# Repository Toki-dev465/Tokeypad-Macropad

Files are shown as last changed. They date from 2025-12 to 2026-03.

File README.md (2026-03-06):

# Important Note
My PCB design has a slight error as the 5V on MC is connected to the VCC of OLED. Using 5V may or may not work. It could potentially damage the microcontroller and the OLED. Flashing QMK is a big pain hence I also made CircuitPython KMK firmware. Will definitely try the QMK firmware when I have time. 
# Description
IBM Model M keyboard themed macropad with a rotary encoder for volume control, 6 keys and a 0.91 inch OLED display. 

# Challenges
It was my first ever electronics project. First time using KiCad, Fusion and QMK. I spent many hours just trying to figure out how to do something by Googling and watching tutorials on YouTube. I had to redesign my schematics, PCB and 3D model numerous times. 3D modeling was much harder than I anticipated at first. Even though I made many errors, I believe this shows my learning progress because you can't learn without making mistakes. 

# Specs/BOM

- 1x XIAO RP2040
- 1x SK6812 MINI Led
- 4x M3x16 Bolt
- 4x M3 Heatset
- 6x Cherry MX Switches
- 6x Blank DSA Keycaps
- 1x I2C OLED Display Module 0.91 Inch SSD1306
- 1x Rotary Encoder Module

| Schematic | PCB Design | 3D Model |
| :---: | :---: | :---: |
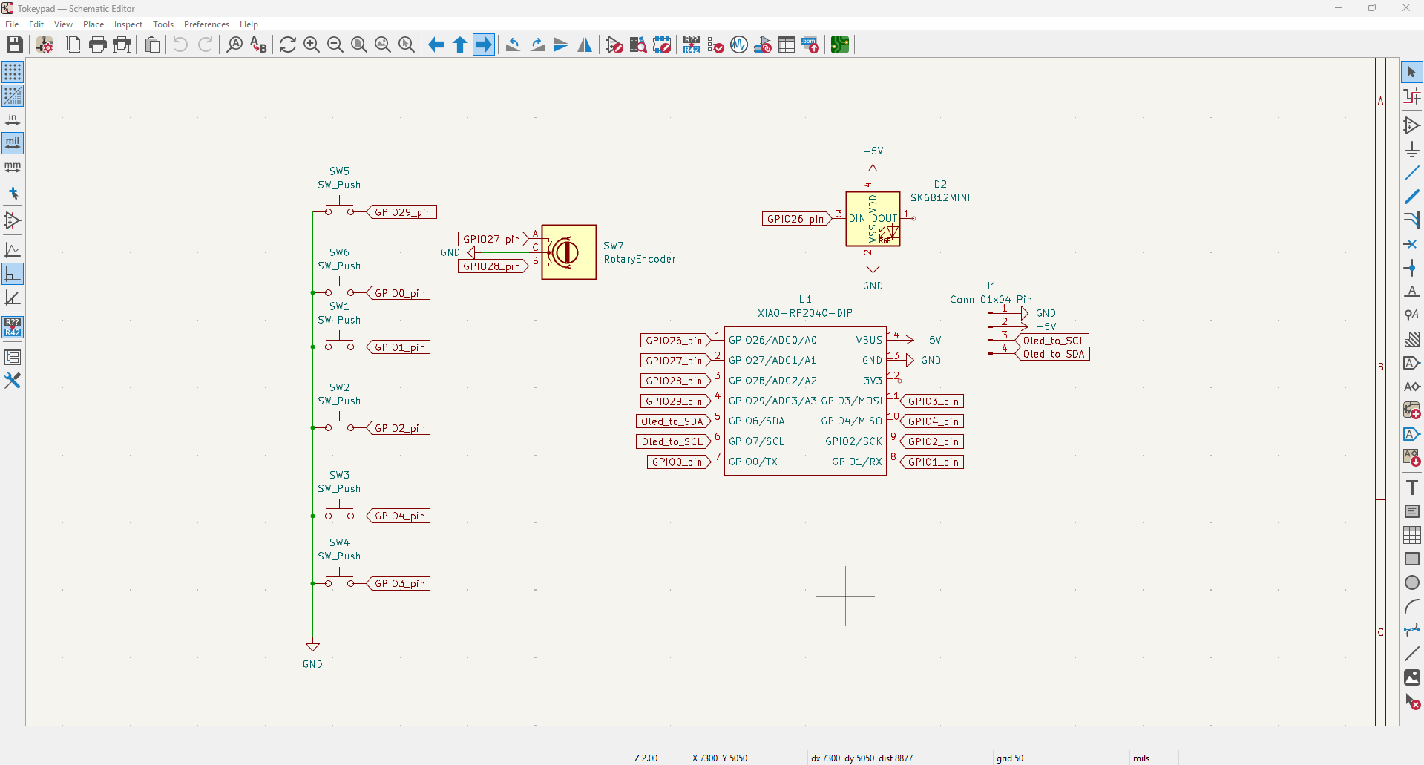
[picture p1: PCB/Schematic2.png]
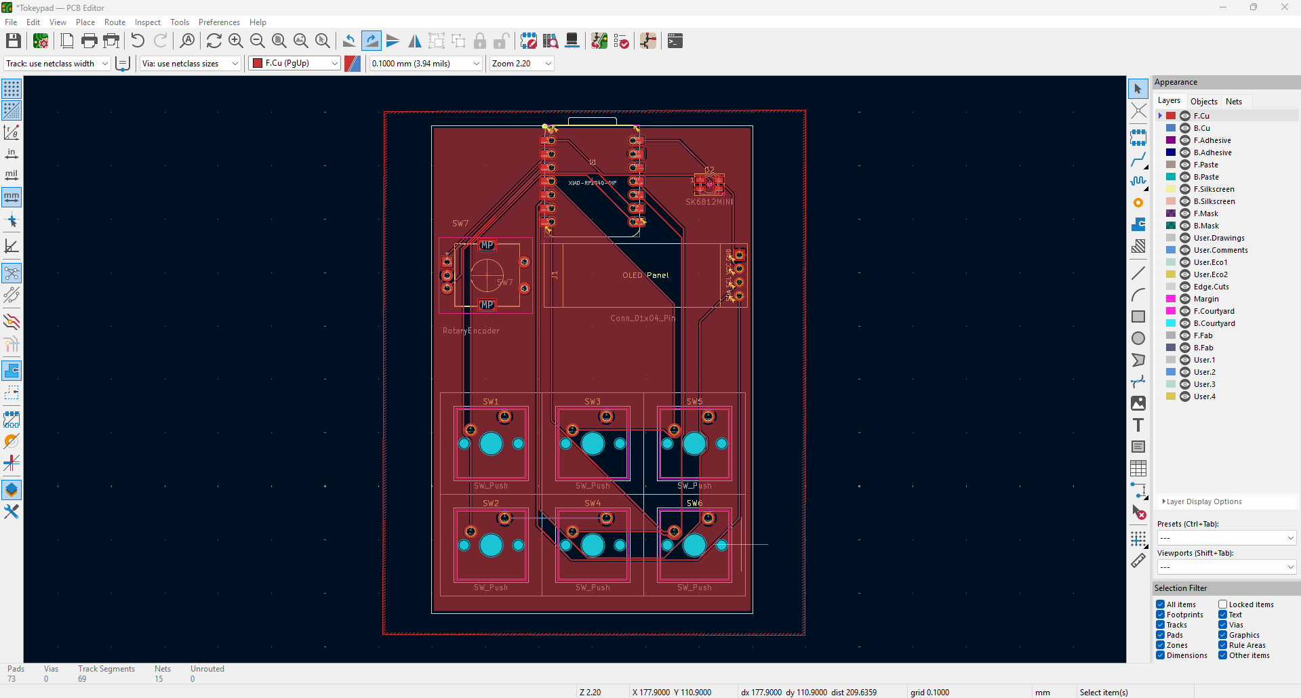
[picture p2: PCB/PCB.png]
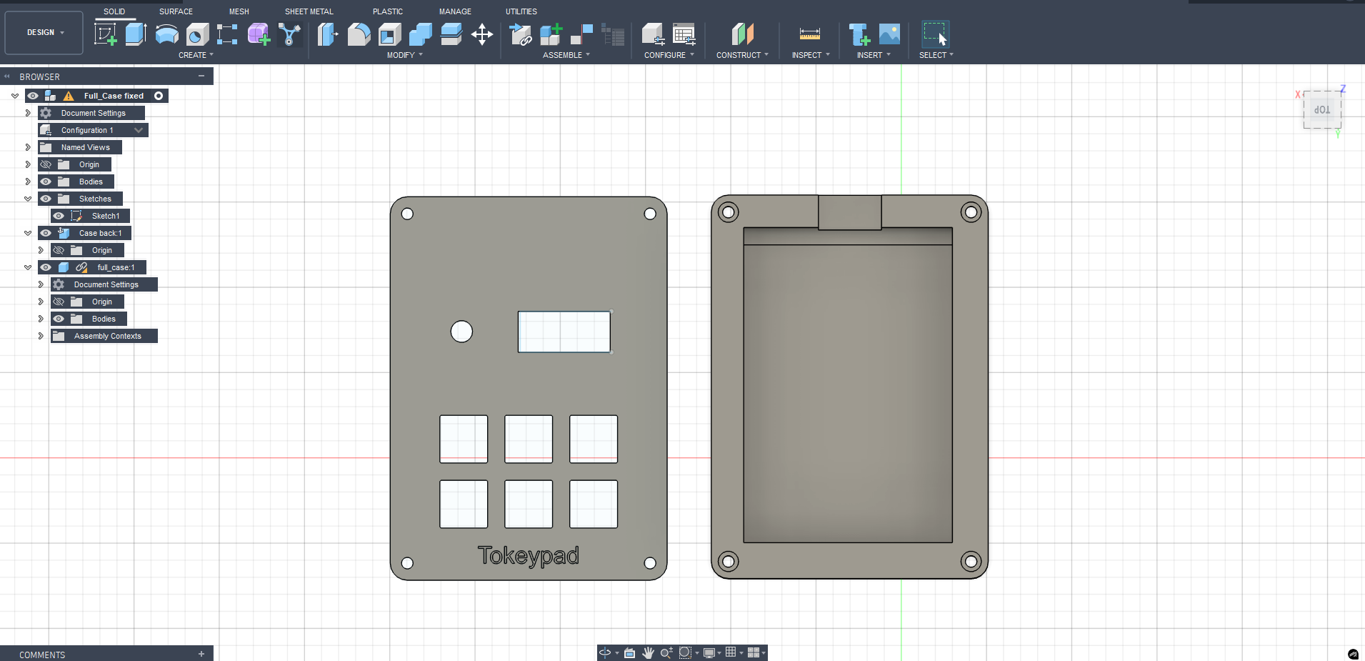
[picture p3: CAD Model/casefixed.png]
|  |  |  |
| *Circuit Diagram* | *Top/Bottom Layers* | *Fusion 360 Render* |

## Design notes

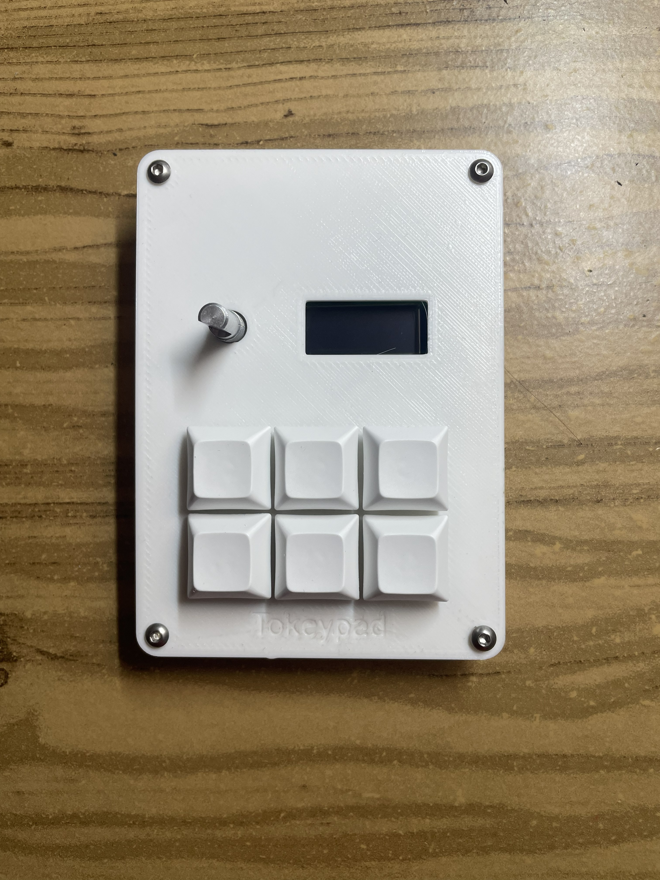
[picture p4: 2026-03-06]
Complete_pics/Tokeypad.jpeg

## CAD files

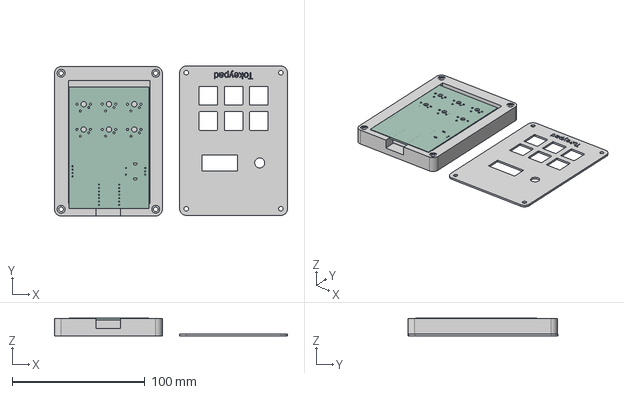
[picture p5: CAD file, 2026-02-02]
CAD Model/Full_Case.step
175.4 x 112.8 x 13.4 mm

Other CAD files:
CAD Model/Full_Case fixed.3mf

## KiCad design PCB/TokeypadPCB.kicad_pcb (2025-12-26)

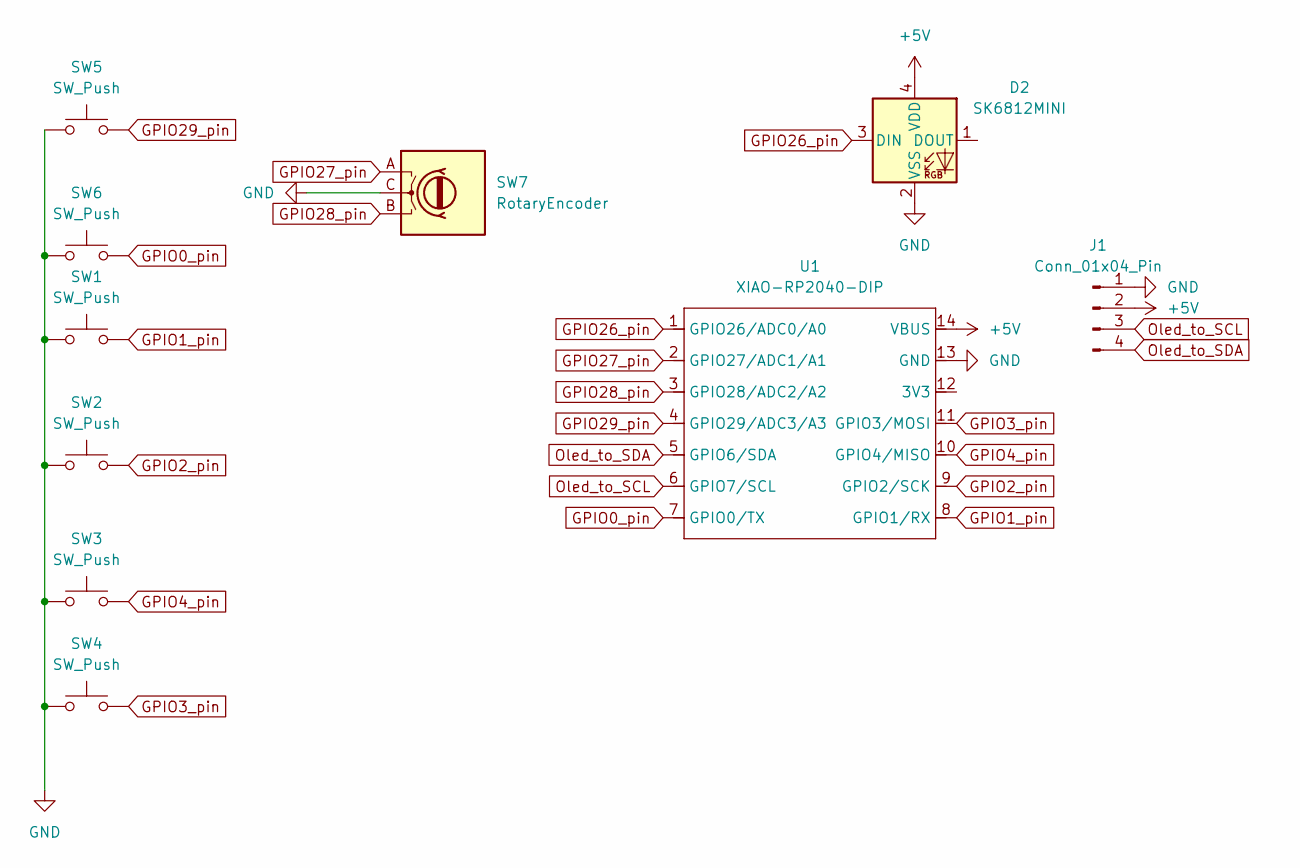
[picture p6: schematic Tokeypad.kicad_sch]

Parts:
D2: SK6812MINI; LED_SK6812MINI_PLCC4_3.5x3.5mm_P1.75mm
J1: Conn_01x04_Pin; NS-Tech_Grove_1x04_P2mm_Vertical
SW1, SW2, SW3, SW4, SW5, SW6: SW_Push; SW_Cherry_MX_1.00u_PCB
SW7: RotaryEncoder; RotaryEncoder_Alps_EC11E-Switch_Vertical_H20mm
U1: XIAO-RP2040-DIP

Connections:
+5V: D2.4 (VDD), J1.2, U1.14 (VBUS)
GND: D2.2 (VSS), J1.1, SW1.1, SW2.1, SW3.1, SW4.1, SW5.1, SW6.1, SW7.C, U1.13 (GND)
GPIO0_pin: SW6.2, U1.7 (GPIO0/TX)
GPIO1_pin: SW1.2, U1.8 (GPIO1/RX)
GPIO2_pin: SW2.2, U1.9 (GPIO2/SCK)
GPIO3_pin: SW4.2, U1.11 (GPIO3/MOSI)
GPIO4_pin: SW3.2, U1.10 (GPIO4/MISO)
GPIO26_pin: D2.3 (DIN), U1.1 (GPIO26/ADC0/A0)
GPIO27_pin: SW7.A, U1.2 (GPIO27/ADC1/A1)
GPIO28_pin: SW7.B, U1.3 (GPIO28/ADC2/A2)
GPIO29_pin: SW5.2, U1.4 (GPIO29/ADC3/A3)
Oled_to_SCL: J1.3, U1.6 (GPIO7/SCL)
Oled_to_SDA: J1.4, U1.5 (GPIO6/SDA)

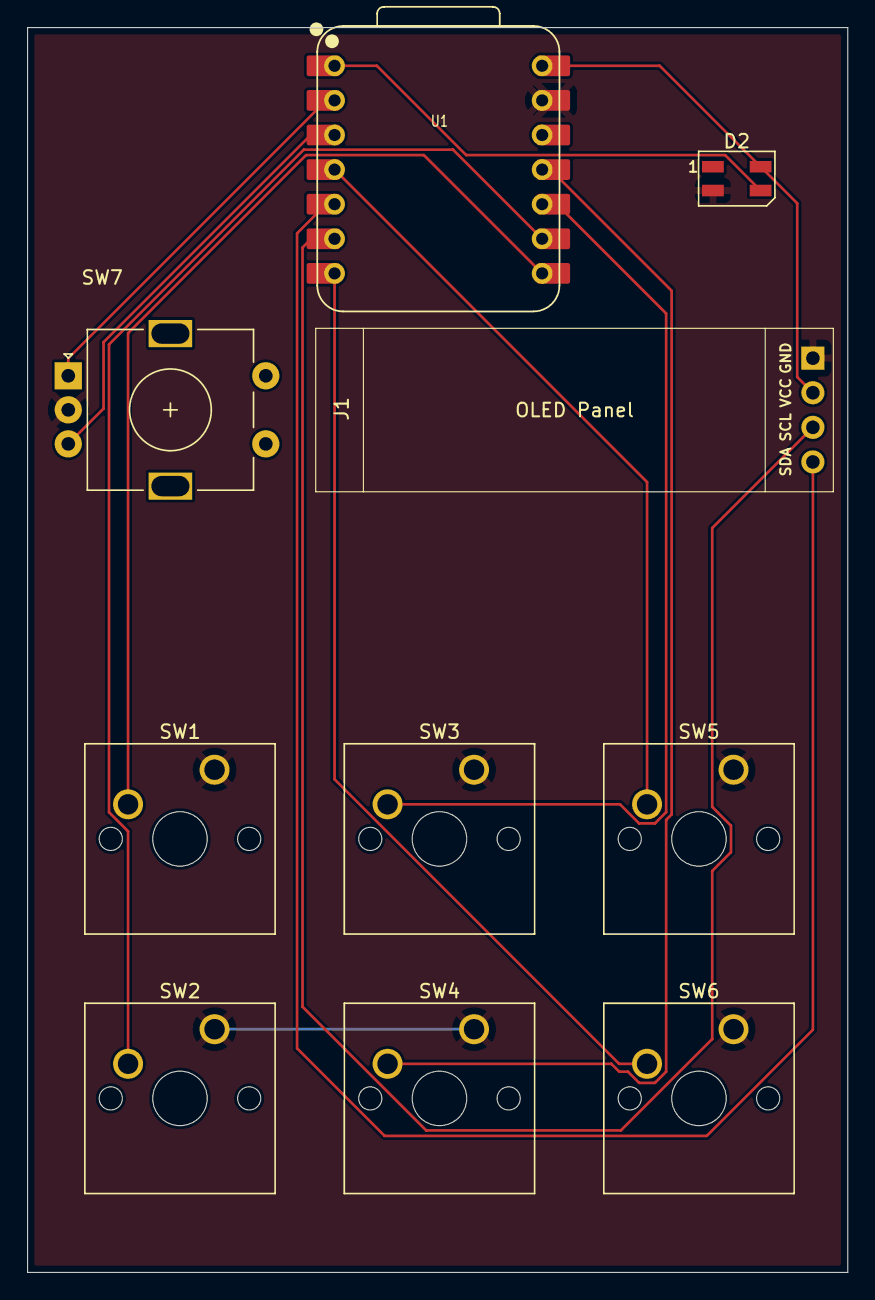
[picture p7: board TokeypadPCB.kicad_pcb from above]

Board: 2 copper layers, 60.2 x 91.4 mm, 10 parts (0 on the bottom side), 13 nets.

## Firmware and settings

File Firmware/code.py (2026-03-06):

import board
import busio
import supervisor
import displayio
import terminalio
import adafruit_displayio_ssd1306
from adafruit_display_text import label

from kmk.kmk_keyboard import KMKKeyboard
from kmk.keys import KC
from kmk.scanners.keypad import KeysScanner
from kmk.modules.encoder import EncoderHandler
from kmk.modules.macros import Macros, Press, Release, Tap, Delay
from kmk.extensions.media_keys import MediaKeys

# OLED
displayio.release_displays()
i2c = busio.I2C(scl=board.D5, sda=board.D4)
display_bus = displayio.I2CDisplay(i2c, device_address=0x3C)
display = adafruit_displayio_ssd1306.SSD1306(display_bus, width=128, height=32)

splash = displayio.Group()
display.show(splash)
oled_label = label.Label(terminalio.FONT, text="", color=0xFFFFFF, x=4, y=14)
splash.append(oled_label)

_oled_clear_at = None

def oled_show(msg, timeout_ms=3000):
    global _oled_clear_at
    oled_label.text = msg
    _oled_clear_at = supervisor.ticks_ms() + timeout_ms

# Keyboard
keyboard = KMKKeyboard()
keyboard.extensions.append(MediaKeys())

macros = Macros()
keyboard.modules.append(macros)

keyboard.matrix = KeysScanner(
    pins=[
        board.D7,   # SW1 -> MUTE
        board.D8,   # SW2 -> PLAY/PAUSE
        board.D9,   # SW3 -> NEXT TRACK
        board.D10,  # SW4 -> PRINT SCREEN
        board.D3,   # SW5 -> WORKFLOW
        board.D6,   # SW6 -> CLOSE ALL
    ],
    value_when_pressed=False,
    pull=True,
)

# Macros
# WORKFLOW: open VSCode + 4 Firefox tabs via Win+R
WORKFLOW = KC.MACRO(
    Press(KC.LGUI), Tap(KC.R), Release(KC.LGUI),
    Delay(300),
    "code\n",
    Delay(1000),

    Press(KC.LGUI), Tap(KC.R), Release(KC.LGUI),
    Delay(300),
    "start firefox https://classroom.google.com\n",
    Delay(500),

    Press(KC.LGUI), Tap(KC.R), Release(KC.LGUI),
    Delay(300),
    "start firefox https://mail.google.com\n",
    Delay(500),

    Press(KC.LGUI), Tap(KC.R), Release(KC.LGUI),
    Delay(300),
    "start firefox https://youtube.com\n",
    Delay(500),

    Press(KC.LGUI), Tap(KC.R), Release(KC.LGUI),
    Delay(300),
    "start firefox https://pomofocus.io/\n",
)

# CLOSE_ALL: Alt+F4 ten times
CLOSE_ALL = KC.MACRO(
    *[step
      for _ in range(10)
      for step in (Press(KC.LALT), Tap(KC.F4), Release(KC.LALT), Delay(250))]
)

# Keymap
keyboard.keymap = [
    [
        KC.MUTE,  KC.MPLY,   KC.MNXT,
        KC.PSCR,  WORKFLOW,  CLOSE_ALL,
    ]
]

# Encoder
encoder_handler = EncoderHandler()
keyboard.modules.append(encoder_handler)
encoder_handler.pins = ((board.D0, board.D1, None, False),)
encoder_handler.map = [((KC.VOLD, KC.VOLU),)]

# OLED
_KEY_LABELS = {
    KC.MUTE:   "Mute",
    KC.MPLY:   "Play/Pause",
    KC.MNXT:   "Next Track",
    KC.PSCR:   "Print Screen",
    WORKFLOW:  "Workflow",
    CLOSE_ALL: "Close All",
}

class OledExtension:
    def during_bootup(self, keyboard):
        oled_show("Ready!", timeout_ms=2000)

    def before_matrix_scan(self, keyboard):
        global _oled_clear_at
        if _oled_clear_at and supervisor.ticks_ms() >= _oled_clear_at:
            oled_label.text = ""
            _oled_clear_at = None

    def after_matrix_scan(self, keyboard): pass

    def before_hid_send(self, keyboard):
        for key in keyboard.keys_pressed:
            msg = _KEY_LABELS.get(key)
            if msg:
                oled_show(msg)
                return

    def after_hid_send(self, keyboard): pass
    def on_powersave_enable(self, keyboard): pass
    def on_powersave_disable(self, keyboard): pass

keyboard.extensions.append(OledExtension())

_orig_move = EncoderHandler.on_move_do

def _enc_move(self, keyboard, state, direction):
    oled_show("Vol Up" if direction > 0 else "Vol Down")
    _orig_move(self, keyboard, state, direction)

EncoderHandler.on_move_do = _enc_move


if __name__ == "__main__":
    keyboard.go()

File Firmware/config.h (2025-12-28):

#pragma once

#define OLED_BRIGHTNESS 128      // set brightness 
#define OLED_TIMEOUT 0           // disable auto screen timeout
#define OLED_DISPLAY_WIDTH 128   // display width
#define OLED_DISPLAY_HEIGHT 32   // display height
#define OLED_DRIVER OLED_IC_SSD1306

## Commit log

2025-11-21 Create Schematic
2025-11-21 Rename Screenshot 2025-11-20 224214.png to Hardware/Schematic
2025-11-21 Rename Screenshot 2025-11-20 224214.png to Hardware/Schematic 224214.png
2025-11-21 Rename Screenshot 2025-11-20 224214.png to Schematic.png
2025-12-28 Created a new directory for only PCB related files for organization purposes
    [Tokeypad.kicad_sch, TokeypadPCB.kicad_pcb]
2026-02-01 Add files via upload
    Fixed version. Holes at the bottom for the screws were unfinished. Made the opening for OLED display smaller.
    [Full_Case fixed.f3z]
2026-03-01 Update README with PCB design error clarification
    Clarified the error in PCB design regarding the 5V connection to the OLED.
2026-03-06 Update README with PCB error details and flashing changes
    Expanded note on PCB design error and flashing issues.
2026-03-06 Create CircuitPython_library
